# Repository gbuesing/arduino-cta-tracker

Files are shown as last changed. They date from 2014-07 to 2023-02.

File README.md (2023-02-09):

# Arduino CTA Tracker

Code and instructions for making an [Arduino Yun](http://arduino.cc/en/Main/ArduinoBoardYun)-based device that shows arrival times for nearby [CTA](http://www.transitchicago.com/) train and bus stops on an LCD.

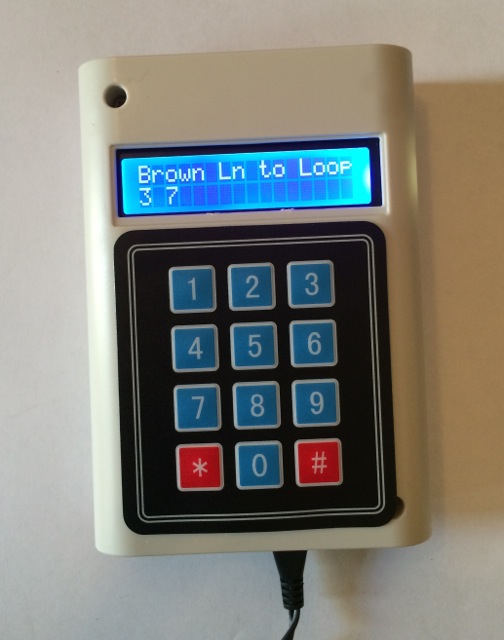
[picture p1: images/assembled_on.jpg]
Assembled and on


Much easier to simply push a button, vs. pulling out my phone, unlocking, finding the Buster app, etc. I've got this device by the front door at home, so that I can time my exit.

Other keys return bus times, weather, current date & time, and a magic 8 ball. Each of the keys run a command line script on the Linux side of the Yun; the string returned on stdout is then displayed on the LCD. So, easy to expand this to return whatever data you find useful.

## Parts needed

- Arduino Yun
- micro-USB power supply for Yun
- Backlit 16x2 LCD screen, with headers soldered on
- Potentiometer (for adjusting LCD screen contrast)
- [3x4 Matrix Keypad](https://www.adafruit.com/product/419)
- Tiny breadboard
- Jumper wires
- [Adafruit Arduino Enclosure](https://www.adafruit.com/products/271)

## CTA API keys

You'll need a [CTA Train Tracker API Key](http://www.transitchicago.com/developers/traintrackerapply.aspx) and a [CTA Bus Tracker API Key](http://www.transitchicago.com/developers/bustracker.aspx). 

Approval for each of these may take a day or two.

## Uploading data scripts to the Yun

The scripts directory in this project contains python scripts for querying CTA train and bus apis, Yahoo weather, and a magic 8 ball. You'll need to upload these to the Linux side of the Yun:

1. Make sure the Yun is connected to Wifi, and that the time zone is set to "America/Chicago" in the configuration.

2. In the scripts directory, copy ```config.py.sample``` to ```config.py``` and add your CTA bus and train API keys.

3. Upload scripts directory to Linux side of Yun via SCP: 

    ```scp -r scripts/ root@arduino.local:/root``` 

4. SSH into Yun: 

    ```ssh root@arduino.local``` 

    and install the python-expat library:

    ```
    opkg update
    opkg install python-expat
    ```

5. While still SSH'd in, test the scripts to make sure they're working:

  ```
  # return times for Southbound Brown line at Irving Park
  python /root/scripts/cta_el.py '30282' 
  ```

  ```
  # return times for Southbound 50 bus at Irving Park
  python /root/scripts/cta_bus.py '50' '8827'
  ```

  To return times for different stops, you'll need the corresponding stop ids; check the comments inside ```cta_el.py``` and ```cta_bus.py``` for instructions.

  If the numbers returned seem excessively large, run ``date`` and confirm that it's returning the correct time in CST. Sometimes after booting up, it takes a minute for the clock to sync.

## Wiring it up

![Wiring diagram](https://raw.githubusercontent.com/gbuesing/yun-cta-train-status/master/images/wiring.png)

## Preparing the sketch and testing

1. Copy constants.h.sample file in this repo to constants.h.

2. In ```constants.h```, change the labels and commands for each key as desired. You'll want to replace stop ids used for ```cta_el.py``` and ```cta_bus.py``` commands to stops near you -- see the top of these files for how to get stop ids.

3. Upload the sketch to the Yun.

4. Wait for "Starting..." message to disappear, and then press a key. The LCD backlight will turn on; the label for the key should immediately appear on the first row, and the results returned from the command on the second row, which may take a second or two.

After five seconds, the LCD backlight will turn off and the screen will be cleared. You can push the button again to query anew.

## Finishing the device

I couldn't find a protoshield that would fit the Yun, so I just wired onto a tiny breadboard that sits on top of the Yun. The small jumper wires going from the breadboard to the Yun header pins keep it in place, so I didn't bother using the sticky on the back of the breadboard.

Note that I'm bending jumper cable pins off to the side, so that everything fits in the case.

![Opened](https://raw.githubusercontent.com/gbuesing/yun-cta-train-status/master/images/opened.jpg)

![Breadboard closeup](https://raw.githubusercontent.com/gbuesing/yun-cta-train-status/master/images/breadboard_closeup.jpg)

The wiring for the keypad is threaded through the opening in the enclosure behind it. The keypad is easily attached to the enclosure via the sticky on back.

![Assembled off](https://raw.githubusercontent.com/gbuesing/yun-cta-train-status/master/images/assembled_off.jpg)

The bottom panel of the enclose doesn't quite match the bottom of the Yun, so I just left it off.

## License

MIT

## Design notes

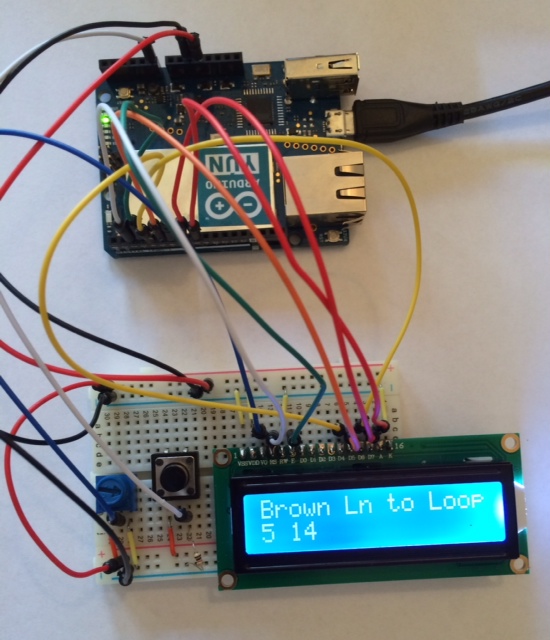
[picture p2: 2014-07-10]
images/prototype.jpg

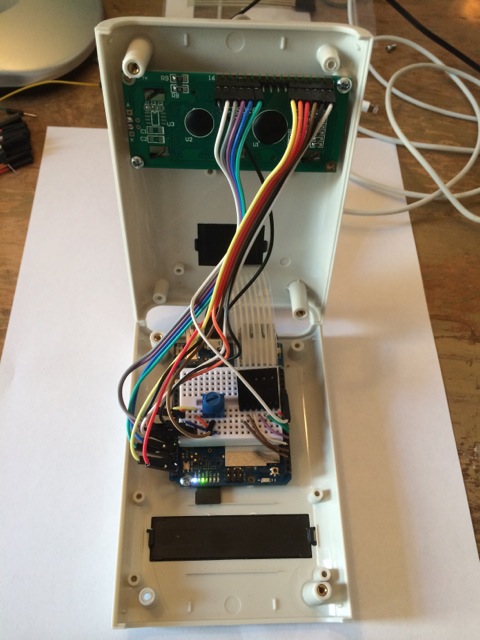
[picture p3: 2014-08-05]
images/opened.jpg

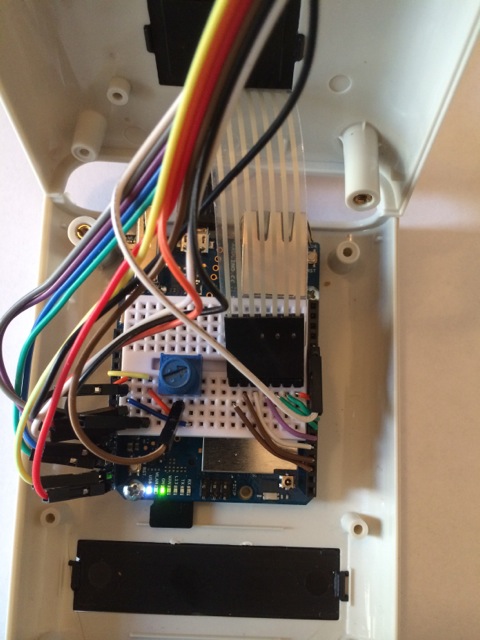
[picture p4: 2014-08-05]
images/breadboard_closeup.jpg

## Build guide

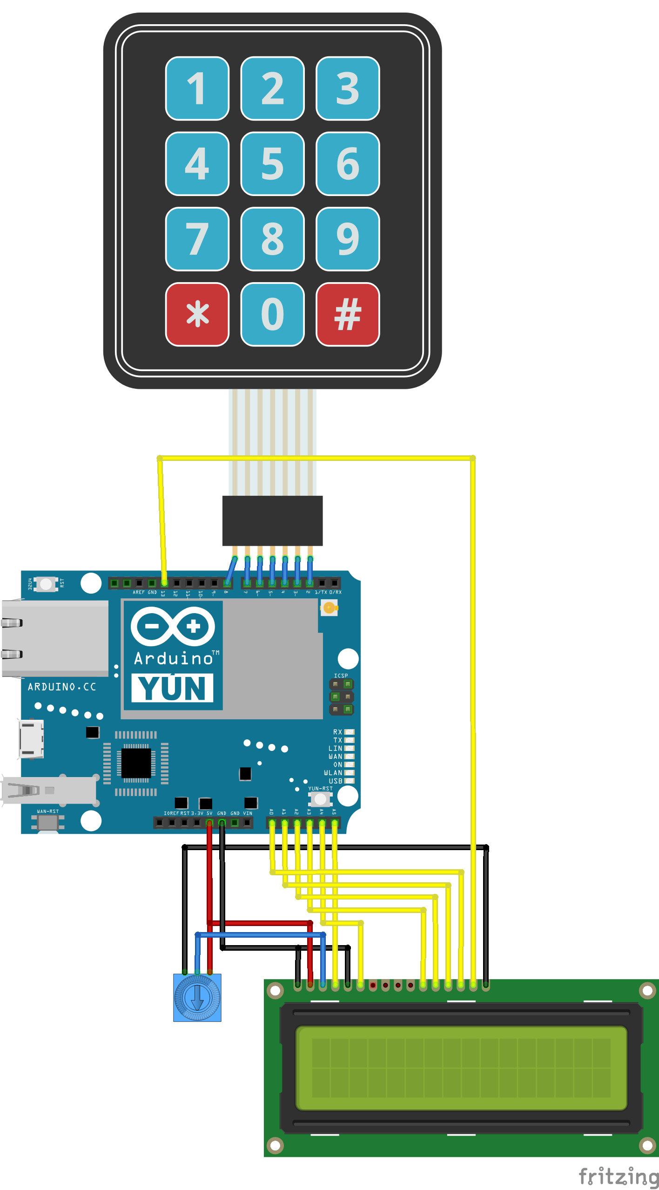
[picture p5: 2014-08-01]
images/wiring.png

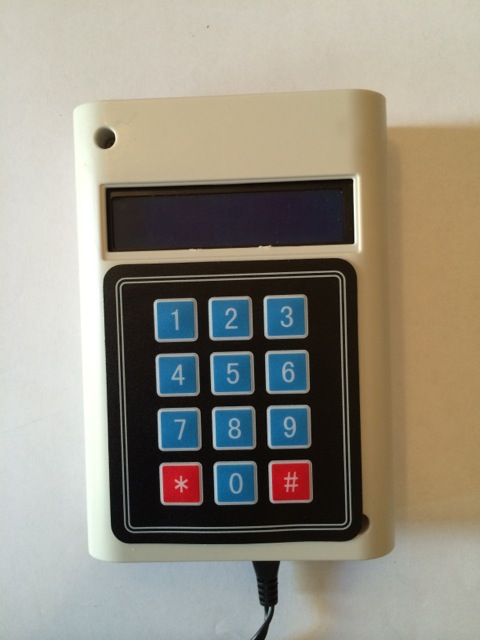
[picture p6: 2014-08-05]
images/assembled_off.jpg

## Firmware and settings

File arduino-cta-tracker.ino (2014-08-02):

#include "Arduino.h"
#include "Keypad.h"
#include <LiquidCrystal.h>
#include <Process.h>
#include "constants.h"


LiquidCrystal lcd(LCD_PINS);

const byte ROWS = 4;
const byte COLS = 3;
char keys[ROWS][COLS] = {
  {'1','2','3'},
  {'4','5','6'},
  {'7','8','9'},
  {'*','0','#'}
};
byte rowPins[ROWS] = {KEYPAD_ROW_PINS}; //connect to the row pinouts of the keypad
byte colPins[COLS] = {KEYPAD_COL_PINS}; //connect to the column pinouts of the keypad

Keypad keypad = Keypad( makeKeymap(keys), rowPins, colPins, ROWS, COLS );


void setup(){
  pinMode(LCD_BACKLIGHT_PIN, OUTPUT);
  lcd.begin(16, 2);
  
  digitalWrite(LCD_BACKLIGHT_PIN, HIGH);
  lcd.print(START_MESSAGE);
  
  Bridge.begin();
  
  digitalWrite(LCD_BACKLIGHT_PIN, LOW);
  lcd.clear();
}
  
void loop(){
  char key = keypad.getKey();
  
  if (key){
    digitalWrite(LCD_BACKLIGHT_PIN, HIGH);
    
    String label = getLabel(key);
    lcd.print(label);
    
    String command = getCommand(key);
    runCommandAndPrint(command);
    
    delay(SHOW_RESULTS_DELAY);
    
    digitalWrite(LCD_BACKLIGHT_PIN, LOW);
    lcd.clear();
  }
}

void runCommandAndPrint(String command) {
  Process p;
  p.runShellCommand(command);
  
  lcd.setCursor(0,1);
  
  while (p.available()>0) {
    char c = p.read();
    if (c != '\n') {
      lcd.write(c);
    }
  }
}

String getLabel(char key) {
  switch ( key ) {
    case '1':
      return KEY_1_LABEL;
    case '2':
      return KEY_2_LABEL;
    case '3':
      return KEY_3_LABEL;
    case '4':
      return KEY_4_LABEL;
    case '5':
      return KEY_5_LABEL;
    case '6':
      return KEY_6_LABEL;
    case '7':
      return KEY_7_LABEL;
    case '8':
      return KEY_8_LABEL;
    case '9':
      return KEY_9_LABEL;
    case '*':
      return KEY_STAR_LABEL;
    case '0':
      return KEY_0_LABEL;
    case '#':
      return KEY_POUND_LABEL;
  } 
}

String getCommand(char key) {
  switch ( key ) {
    case '1':
      return KEY_1_COMMAND;
    case '2':
      return KEY_2_COMMAND;
    case '3':
      return KEY_3_COMMAND;
    case '4':
      return KEY_4_COMMAND;
    case '5':
      return KEY_5_COMMAND;
    case '6':
      return KEY_6_COMMAND;
    case '7':
      return KEY_7_COMMAND;
    case '8':
      return KEY_8_COMMAND;
    case '9':
      return KEY_9_COMMAND;
    case '*':
      return KEY_STAR_COMMAND;
    case '0':
      return KEY_0_COMMAND;
    case '#':
      return KEY_POUND_COMMAND;
  } 
}

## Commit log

2014-07-10 add breadboard wiring diagram
2014-07-10 Fix wiring diagram
2014-07-10 Add photo of breadboarded prototype to README
2014-07-31 cta el script: don't bother passing in key. Rename to cta_el.py
2014-07-31 weather.py: return current, forecast and sunset based on argv
2014-07-31 fix el script
2014-08-01 update wiring diagram
    [wiring.fzz]
2014-08-04 Get api keys for scripts from config.py. Add config.py.sample, so that actual keys aren't checked into source control
